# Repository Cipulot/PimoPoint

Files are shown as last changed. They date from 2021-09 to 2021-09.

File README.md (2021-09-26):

# PimoTrack Extras

This repository contains code and custom mounting hardware files for the [Pimoroni Trackball Breakout](https://shop.pimoroni.com/products/trackball-breakout).

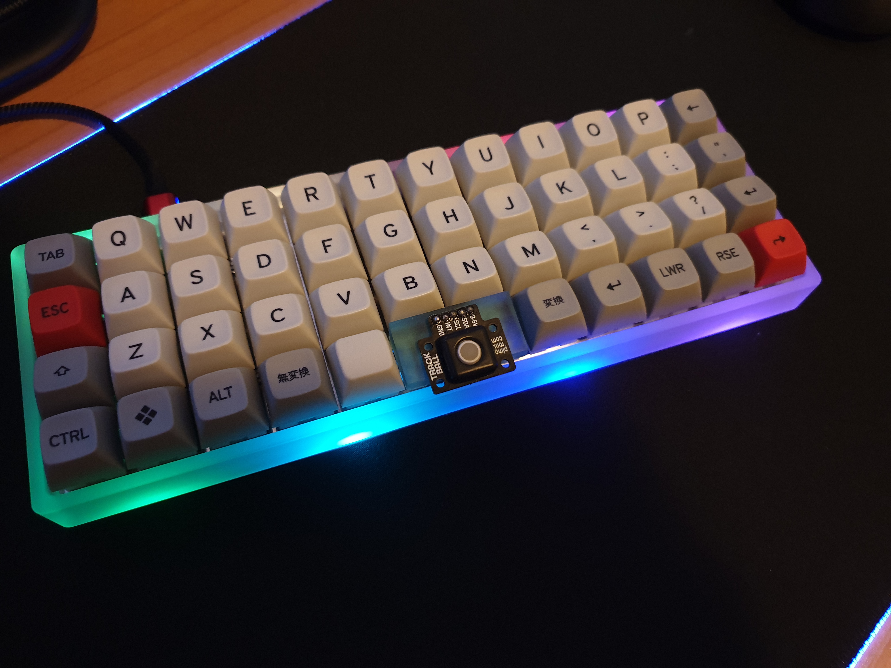
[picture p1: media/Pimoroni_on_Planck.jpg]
Pimoroni on Planck


## Firmware

While QMK natively supports trackball modules over I²C, the base support is somewhat limited at the moment and requires a bit of tinkering to get other functions.
This is why I've created a custom set of firmware files for the Track Ball Breakout that include basic but user friendly features.

### `config.h`

Here you can specify the orientation of the module using `TRACKBALL_ORIENTATION` and the angle of the trackball using `TRACKBALL_ANGLE`.

### `pimoroni_trackball.c`

File containing the actual code for the trackball. Here you'll add code to your personally defined functions if you want to expand the functionality of the trackball. Remember to add function prototype to `pimoroni_trackball.h`.

### `pimoroni_trackball.h`

Header file for the trackball firmware. Contains defines for I²C address of the module, addresses for I²C write and read, along with other addresses, function prototypes and struct for trackball state.

If you changed the I²C address of the module, you'll need to change `#define TRACKBALL_ADDRESS 0x0A` to `#define TRACKBALL_ADDRESS 0x0B`.

### `keymap.c`

Example keymap that shows how to implement the trackball functionality into your keymap.
For further explanations see the comments in the code itself.

### `rules.mk`

Rules that you'll add to personal keymap.

Having `PIMORONI_TRACKBALL_ENABLE = yes` will automatically enable pointing device capabilities through `POINTING_DEVICE_ENABLE = yes` and add required files to the build process (`SRC += pimoroni_trackball.c` and the Quantum I²C lib, `QUANTUM_LIB_SRC += i2c_master.c`).

## Hardware

The Pimoroni Trackball Breakout PCB is a small breakout board with exposed I²C pins and 4 mounting holes.

Dimensional measurements:
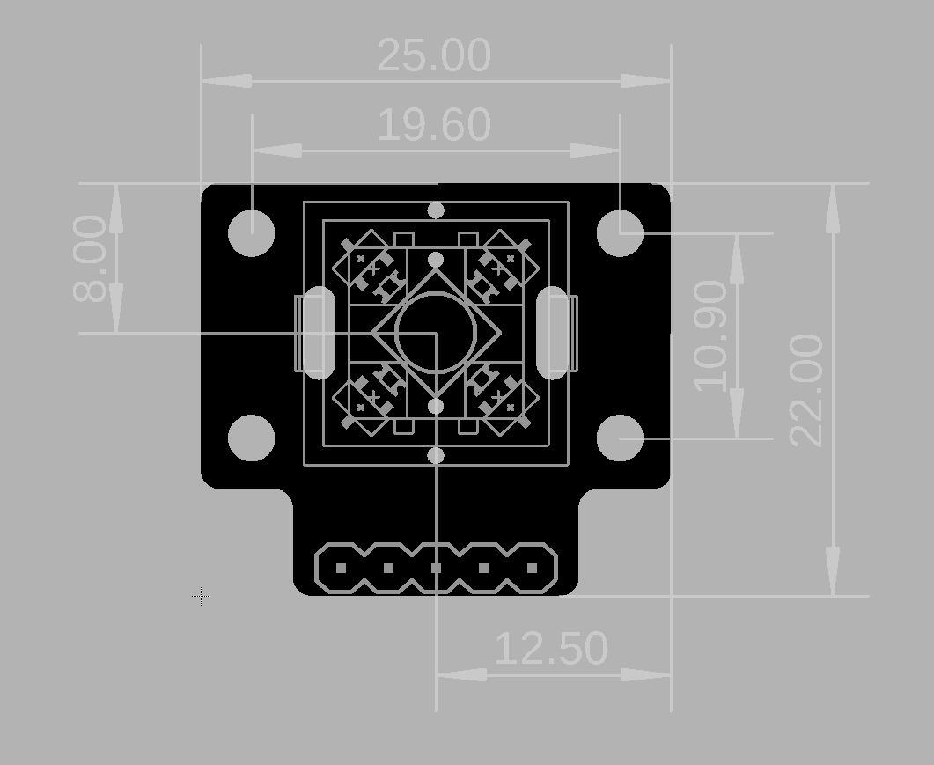
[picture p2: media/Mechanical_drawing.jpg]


Unfortunately, while being relatively small, the PCB is not small enough to be used in a 1U sized space.

I've therefore designed an angled mounting bracket that can be used to mount the PCB in a 2U sized space.

It uses 2 Cherry MX style switches, without top casing and glued stems, as mounting points.
This allows for smaller and easier to print parts both with FDM and SLA printers, since smaller parts as the clips for plate clip-in would require high degree of accuracy.

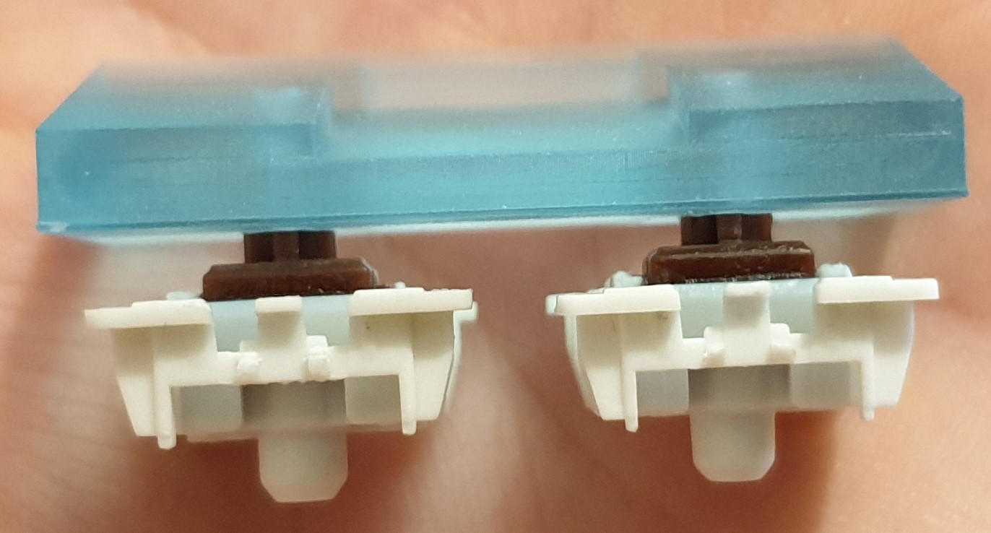
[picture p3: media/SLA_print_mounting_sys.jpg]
SLA_print_mounting_sys


### Trackball support w_ fix holes

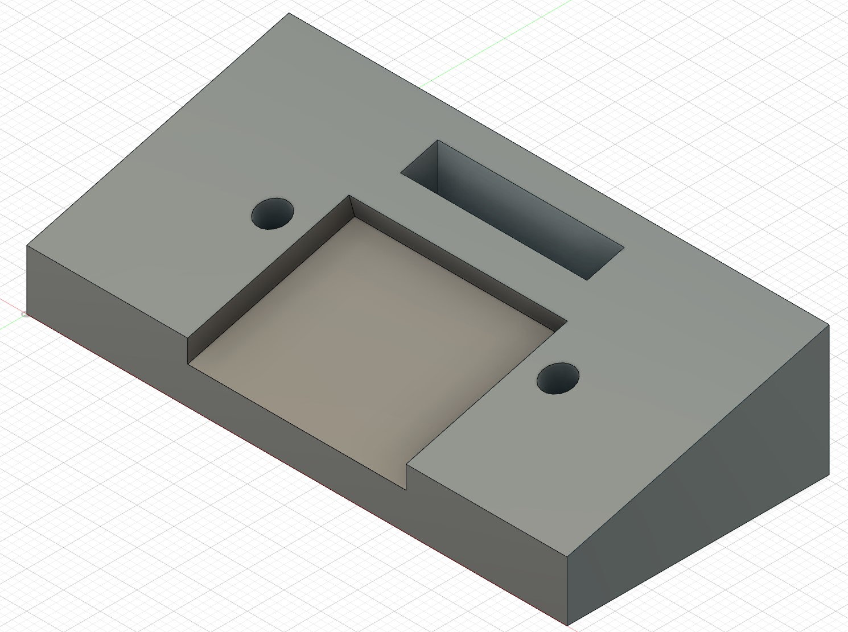
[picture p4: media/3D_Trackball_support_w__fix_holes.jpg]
w_ fix holes


### Trackball support w_o fix holes

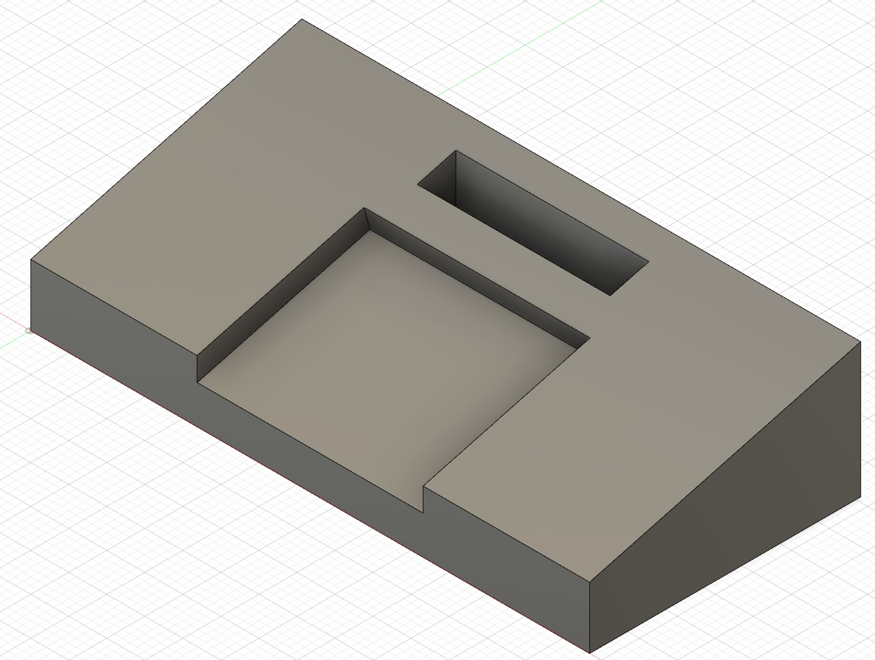
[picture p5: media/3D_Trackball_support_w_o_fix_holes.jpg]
w_o fix holes


### Fabrication example

Here's a collection of printed parts using SLA print method.

Support w_ fix holes top view:
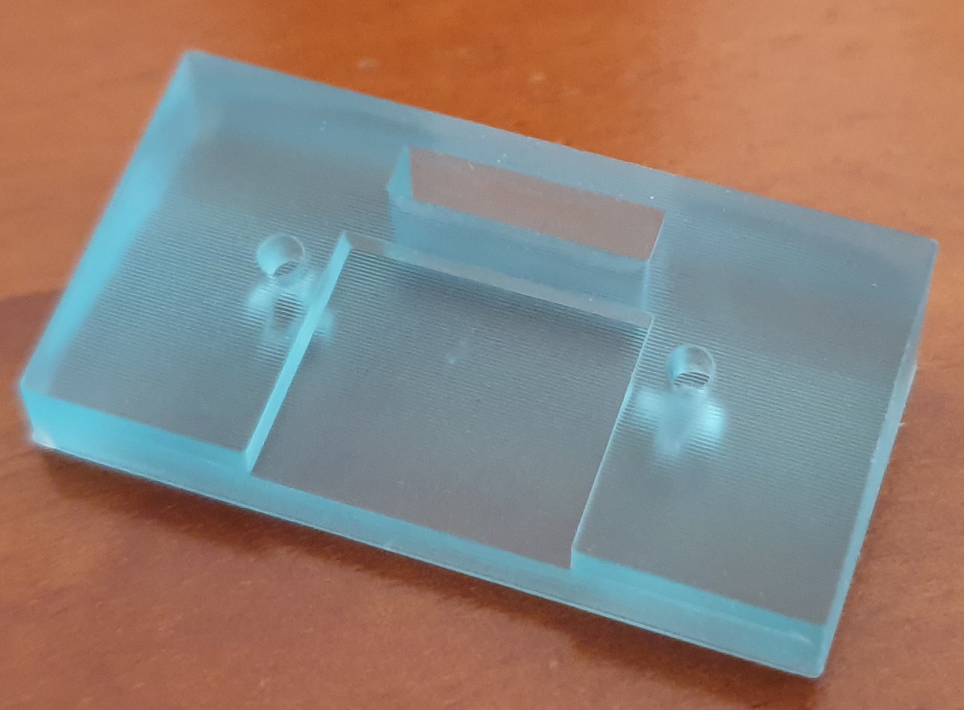
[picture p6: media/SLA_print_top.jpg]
SLA_print_top


Support w_ fix holes bot view:
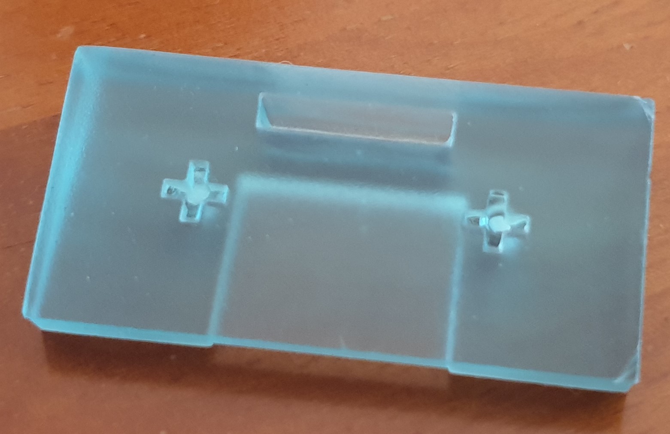
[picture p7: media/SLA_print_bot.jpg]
SLA_print_bot


Support w_ fix holes with pin strip receptor:
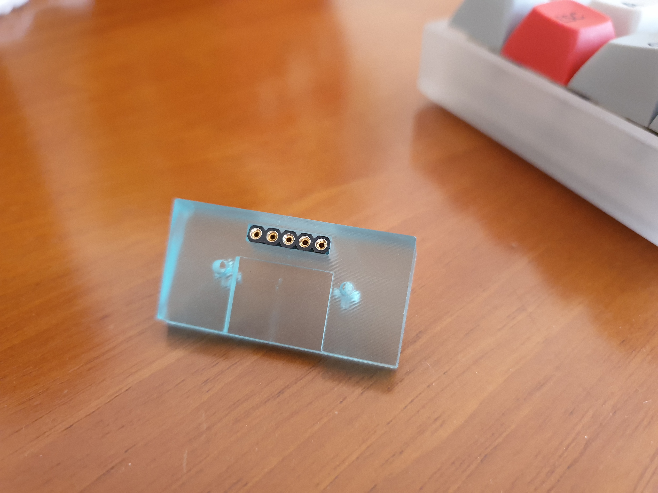
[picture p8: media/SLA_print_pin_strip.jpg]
SLA_print_pin_strip_receptor


Planck with Trackball Breakout PCB mounted on support:
<p float="left">
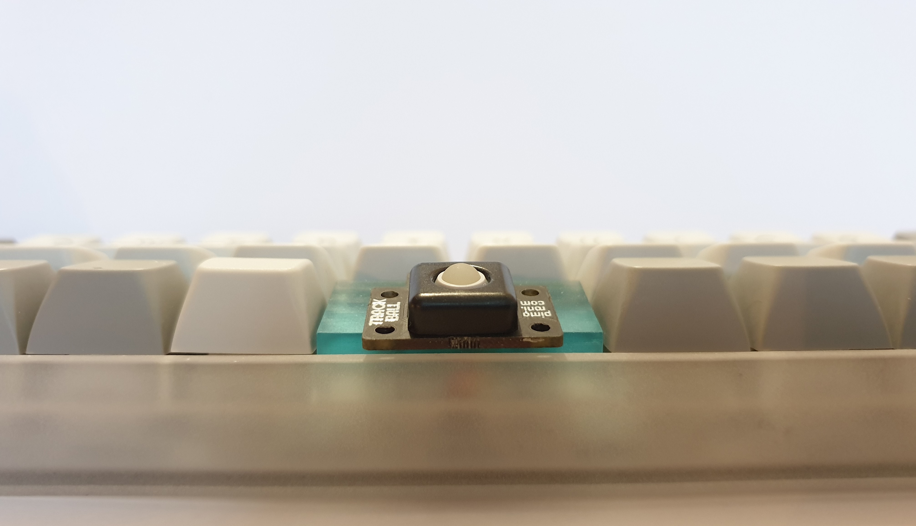
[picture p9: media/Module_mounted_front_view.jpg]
  
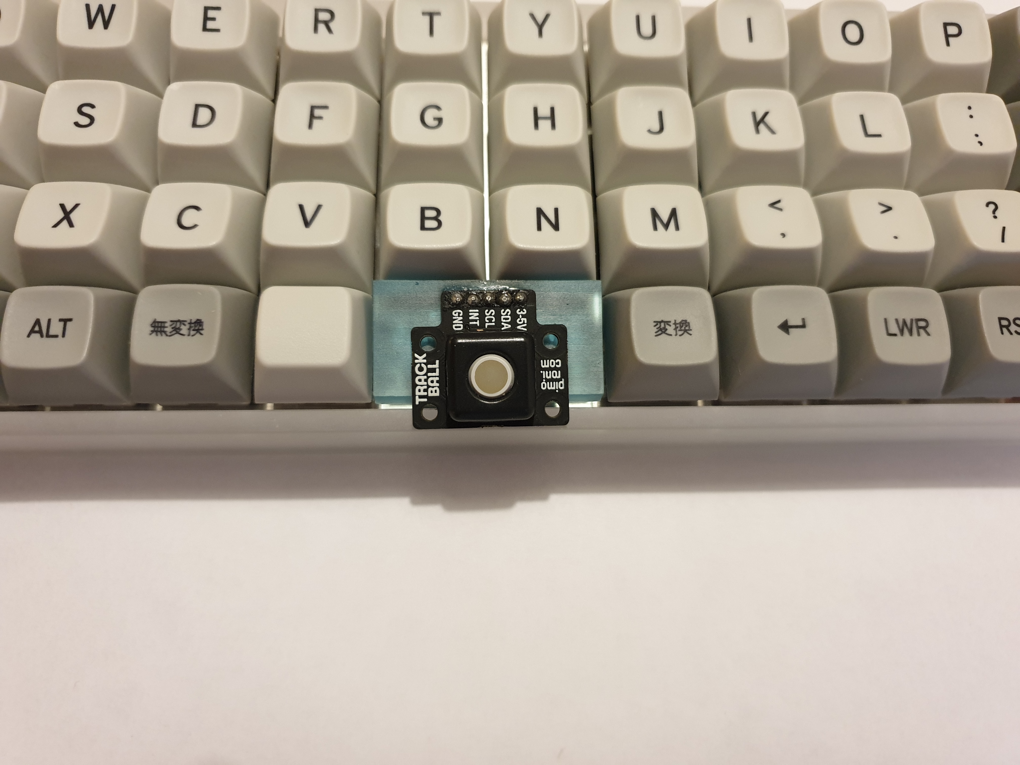
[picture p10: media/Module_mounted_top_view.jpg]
  
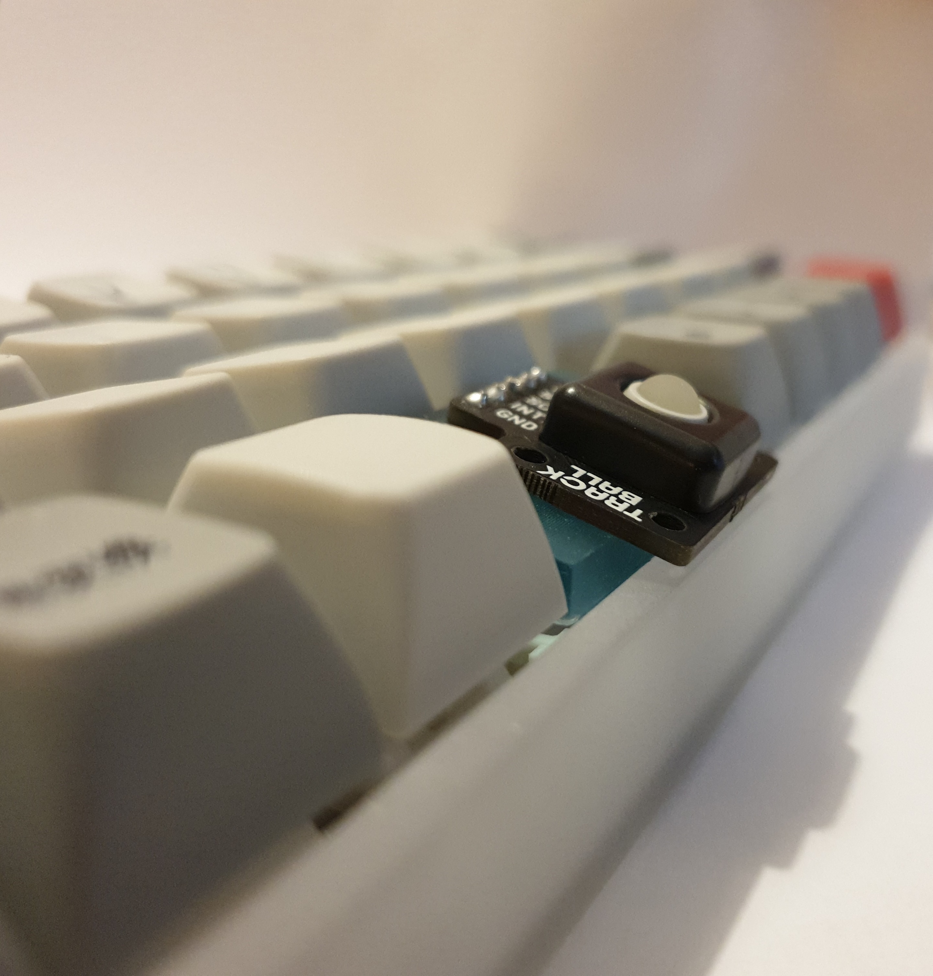
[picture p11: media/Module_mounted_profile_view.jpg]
  
</p>

## Future features and improvements

These are the things I'd like to improve in the future:

* 3D model a replacement cover for the trackball, for further customization.

* Create a new support for the Trackball Breakout with a different mounting system. This would allow for a more flexible and user friendly installation since it will not require the use of 2 "sacrificial" switches.

  The actual design wouldn't require much changes to the model in use today but considerations must be made in order to make it printable by the average FDM and SLA printers. Generally available FDM printers are not as good as SLA printers and therefore the design would need to be adjusted to make it printable. Durability is another concern that will be investigated once early design is done.

* Make a custom 1U sized space PCB, allowing for a more flexible use by the end user, since it will free up a 1U compared to today's standard 2U sized space.

  The challenging part is the sourcing of raw materials and the design of the PCB. The actual PCB is quite easy to design, since space can be saved by removing the mounting holes and the exposed I²C pins can be swapped for small solder pads. The actual firmware onboard the MCU doesn't appear to be public. This means that it would need to be provided by the Pimoroni team or dumped in some way from a genuine Pimoroni device and later flashed to virgin MCUs.

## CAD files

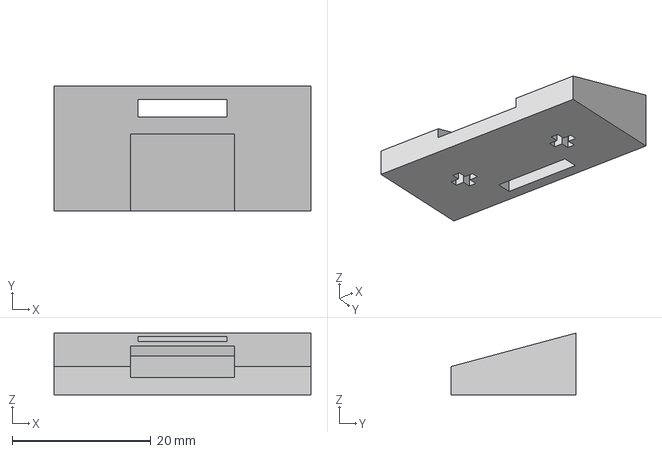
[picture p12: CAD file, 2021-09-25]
Hardware/Trackball support w_o fix holes.3mf
37.1 x 18.0 x 8.92 mm

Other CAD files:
Hardware/Trackball support w_ fix holes.3mf
Hardware/Trackball support w_ fix holes.stl
Hardware/Trackball support w_o fix holes.stl

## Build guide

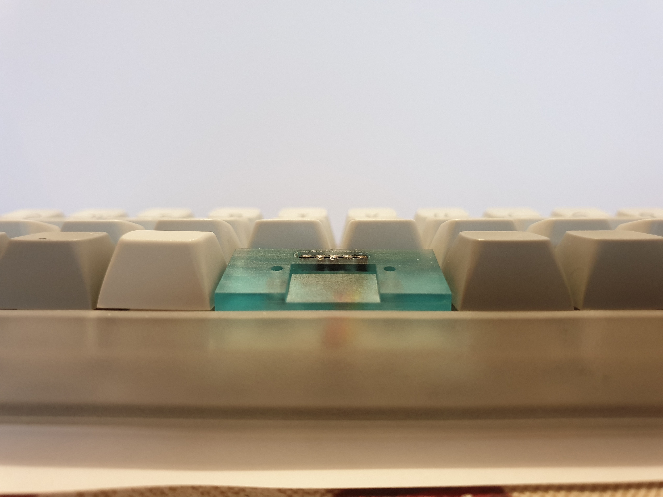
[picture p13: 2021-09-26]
media/SLA_print_front_view.jpg

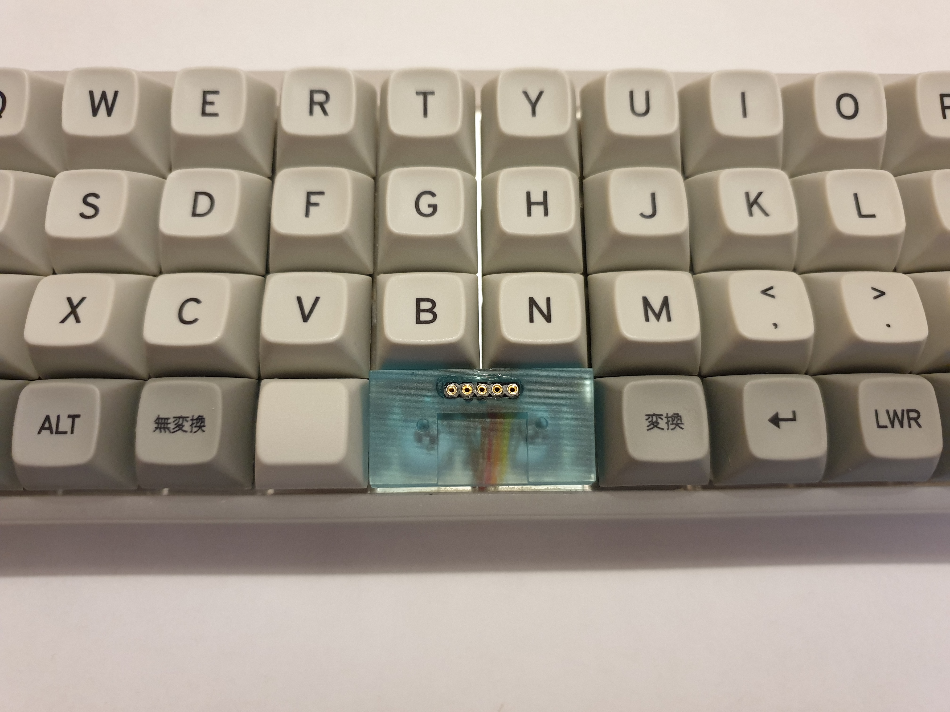
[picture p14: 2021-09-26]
media/SLA_print_top_view.jpg

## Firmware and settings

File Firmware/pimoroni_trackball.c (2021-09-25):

#include "pimoroni_trackball.h"
#include "i2c_master.h"

#ifdef TRACKBALL_WITH_MATH
#include "math.h"
#ifndef TRACKBALL_ANGLE_OFFSET
#define TRACKBALL_ANGLE_OFFSET 0
#endif
#endif

#ifndef TRACKBALL_ORIENTATION
#define TRACKBALL_ORIENTATION 0
#endif

void trackball_init(void)
{
    i2c_init();
#ifdef TRACKBALL_INTERRUPT_PIN
    setPinInput(TRACKBALL_INTERRUPT_PIN);
    writePinLow(TRACKBALL_INTERRUPT_PIN);
    uint8_t data[] = {REG_INTERRUPT_PIN, MASK_INTERRUPT_PIN_ENABLE};
    i2c_transmit(TRACKBALL_WRITE, data, 2, TB_I2C_TIMEOUT);
#endif
}

bool trackball_get_interrupt(void)
{
#ifndef TRACKBALL_INTERRUPT_PIN
    uint8_t data[1] = {};
    i2c_readReg(TRACKBALL_WRITE, REG_INTERRUPT_PIN, data, 1, TB_I2C_TIMEOUT);

    return data[0] & MASK_INTERRUPT_TRIGGERED;
#else
    return !readPin(TRACKBALL_INTERRUPT_PIN);
#endif
}

void trackball_set_rgbw(uint8_t red, uint8_t green, uint8_t blue, uint8_t white)
{
    uint8_t data[] = {0x00, red, green, blue, white};
    i2c_transmit(TRACKBALL_WRITE, data, 5, TB_I2C_TIMEOUT);
}

void trackball_read_state(uint8_t *data, uint16_t size_of_data)
{
    i2c_readReg(TRACKBALL_WRITE, REG_LEFT, data, size_of_data, TB_I2C_TIMEOUT);
}

trackball_state_t trackball_get_state(void)
{
    // up down left right button
    uint8_t s[5] = {};
    trackball_read_state(s, 5);

    trackball_state_t state = {
#if TRACKBALL_ORIENTATION == 0
        // Trackball text is up
        .y = s[0] - s[1],
        .x = s[3] - s[2],
#elif TRACKBALL_ORIENTATION == 1
        // Trackball text is right
        .y = s[3] - s[2],
        .x = s[1] - s[0],
#elif TRACKBALL_ORIENTATION == 2
        // Trackball text is down
        .y = s[1] - s[0],
        .x = s[2] - s[3],
#else
        // Trackball text is left
        .y = s[2] - s[3],
        .x = s[0] - s[1],
#endif
        .button_down = s[4] & 0x80,
        .button_triggered = s[4] & 0x01,
    };

#ifdef TRACKBALL_WITH_MATH
    state.angle_rad = atan2(state.y, state.x) + TRACKBALL_ANGLE_OFFSET;
    state.vector_length = sqrt(pow(state.x, 2) + pow(state.y, 2));
    state.raw_x = state.x;
    state.raw_y = state.y;
    state.x = (int16_t)(state.vector_length * cos(state.angle_rad));
    state.y = (int16_t)(state.vector_length * sin(state.angle_rad));
#endif

    return state;
}

void trackball_sleep(void)
{
    uint8_t data[] = {REG_CTRL, MSK_CTRL_FWRITE | MSK_CTRL_SLEEP};
    i2c_transmit(TRACKBALL_WRITE, data, 2, TB_I2C_TIMEOUT);
}

void trackball_set_brightness(uint8_t brightness)
{
    uint8_t data[4] = {};
    i2c_readReg(TRACKBALL_WRITE, REG_RED, data, 4, TB_I2C_TIMEOUT);
    for (int i = 0; i < 4; i++)
    {
        if (data[i])
        {
            data[i] = brightness;
        }
    }
    i2c_writeReg(TRACKBALL_WRITE, REG_RED, data, 4, TB_I2C_TIMEOUT);
}

#ifndef MIN
#define MIN(a, b) ((a) < (b) ? (a) : (b))
#endif
void trackball_set_hsv(uint8_t hue, uint8_t sat, uint8_t brightness)
{
    RGB rgb = hsv_to_rgb((HSV){hue, sat, brightness});
    uint8_t white = MIN(rgb.r, MIN(rgb.g, rgb.b));
    rgb.r -= white;
    rgb.g -= white;
    rgb.b -= white;

    trackball_set_rgbw(rgb.r, rgb.g, rgb.b, white);
}

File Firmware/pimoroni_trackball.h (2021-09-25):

#pragma once

#include <quantum.h>
#include "color.h"

#ifndef TRACKBALL_ADDRESS
#define TRACKBALL_ADDRESS 0x0A
#endif

#ifndef TRACKBALL_ANGLE_OFFSET
#define TRACKBALL_ANGLE_OFFSET 0
#endif

#define I2C_WRITE 0x00
#define TRACKBALL_WRITE ((TRACKBALL_ADDRESS << 1) | I2C_WRITE)
#define TRACKBALL_READ ((TRACKBALL_ADDRESS << 1) | I2C_READ)

#define TB_I2C_TIMEOUT 100

#define REG_RED 0x00
#define REG_GREEN 0x01
#define REG_BLUE 0x02
#define REG_WHITE 0x03

#define REG_LEFT 0x04

#define REG_INTERRUPT_PIN 0xF9
#define MASK_INTERRUPT_TRIGGERED 0x01
#define MASK_INTERRUPT_PIN_ENABLE 0x02

#define REG_CTRL 0xFE
#define MSK_CTRL_SLEEP 0b00000001
#define MSK_CTRL_RESET 0b00000010
#define MSK_CTRL_FREAD 0b00000100
#define MSK_CTRL_FWRITE 0b00001000

typedef struct
{
    int16_t x;
    int16_t y;
    bool button_down;
    bool button_triggered;
#ifdef TRACKBALL_WITH_MATH
    double vector_length;
    double angle_rad;
    int8_t raw_x;
    int8_t raw_y;
#endif
} trackball_state_t;

void trackball_init(void);
bool trackball_get_interrupt(void);
void trackball_set_rgbw(uint8_t r, uint8_t g, uint8_t b, uint8_t w);
void trackball_read_state(uint8_t *data, uint16_t size_of_data);
void trackball_sleep(void);
void trackball_set_brightness(uint8_t brightness);
void trackball_set_hsv(uint8_t hue, uint8_t sat, uint8_t brightness);

trackball_state_t trackball_get_state(void);
